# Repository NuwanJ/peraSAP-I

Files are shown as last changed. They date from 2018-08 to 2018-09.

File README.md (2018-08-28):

Image of Yaktocat

## Pera SAP-I Computer

Does anyone have an idea about early computers? The age before Microcontrollers/ Microprocessors? I have just now completed a project that takes me into that time. 

This is an 8-bit Minimum Computer (Computation Machine) [1] that made from simple logic ICs, flip-flops and a few memory modules. It has a memory of 16 bytes and its maximum clock speed is not more than 5 Hz.

The whole design is based on SAP-I Architecture and design was obtained from Ben Eater’s Youtube Channel [2]. Currently, it has 9 instructions (based on Intel 8080 instructions) and can be programmed it using machine language (That means programming from 1s and 0s)

The project was started as a project for CO221: Digital Design Course, Department of Computer Engineering, University of Peradeniya.

All the Printed Circuit boards were designed from the basics by us using Fritzing, fabricated by using the CNC, Builder_V3 and soldered and assembled by us. It took 2 months to complete the fabrications and another month for build motherboard (30x40cm) and debugging.

After the evolution of the project, we hope to make it free and open source under Apache License 2.0

##### Special thanks to
- Dr. Kamalanath Samarakoon for giving the idea & source materials about SAP-I
Dr. S.D. Dewasurendra
- Miss. Narmada Balasooriya, Miss. Thilini Dahanayaka and all the instructors on the Department of Computer Engineering
- My team members; Suneth Samarasinghe, Pubudu Premathilake, Dilshani Karunarathne, Wishma Herath, Pasan Thennakoon & Irfan Mohommad

##### References:
- [Computer algorithms - Wikipedia ](https://en.wikipedia.org/wiki/Algorithm#Computer_algorithms)
- [Building an 8-bit breadboard computer! - Youtube](https://www.youtube.com/playlist?list=PLowKtXNTBypGqImE405J2565dvjafglHU)
- [Open source project files- Github](https://github.com/NuwanJ/peraSAP-I)
 - [Project Page](http://nuwanjaliyagoda.esy.es/projects/8bit-computer)

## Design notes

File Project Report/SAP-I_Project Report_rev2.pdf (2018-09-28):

CO221: Digital Design - Hardware Project

# SAP-I Computer from discrete components

Project Team:

- Jaliyagoda A.J.N.M. (E/15/140)
- Herath H.M.M.E.W.L. (E/15/123)
- Karunarathna S.D.D.D. (E/15/173)
- Samarasinghe U.G.S.B. (E/15/316)
- Premathilaka M.P.U. (E/15/280)
- Irfan M.M.M. (E/15/138)
- Tennakoon T.M.P.B. (E/15/350)

## Contents

1. Introduction
2. Design Procedure
2.1. Modules
2.1.1. Clock Module
2.1.2. Program Counter
2.1.3. Registers
2.1.4. Arithmetic and Logic Unit
2.1.5. Output Register
2.1.6. RAM and Programmer
2.1.7. Control Sequencer
2.1.8. Motherboard and the Data Bus
2.2. Programs and Additional Hardware
2.2.1. EEPROM Programmer
2.2.2. Assembly Language Instructions
3. Results
4. Expenditures
5. Conclusions and future works
6. References
7. Appendix
7.1. Schematics Diagrams
7.2. Project Repository
7.3. Project Page

## 1. Introduction

“SAP” is the shortened form of “Simple As Possible”. SAP-1 is the first stage in the evolution of the modern computers. This design contains all the most essential components of a modern computer and it covers many advanced concepts in Computer Architecture.

SAP-1 is a bus organized computer. All the components are connected with a single 8-bit bus (W) through tri-state buffers.

Specifications:
- 8-bit Bus
- 4-bit Program Counter
- 4-bit Memory Address Register (MAR)
- 16-byte Memory
- 8-bit Instruction Register (IR)
- 5 cycle micro-instructions with 16-bit words
- 8-bit Accumulator
- 8-bit B register
- 8-bit Full Adder/ Subtractor
- 8-bit Output Register

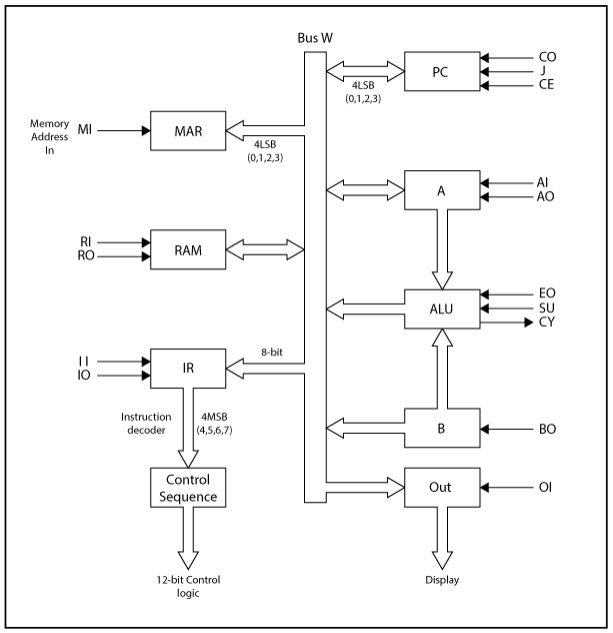
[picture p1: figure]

Figure 1.1: SAP-1 Organization

## 2. Design Procedure

### 2.1 Modules

All the modules were separately designed, fabricated and finally connected each other on a single circuit board; motherboard which includes all the data and signal buses

Here is the list of modules we were designed

- Clock Module
- Program Counter
- Registers (Register A, Register B, Instruction Register)
- Arithmetic and Logic Unit (ALU)
- Output Register
- RAM and Programmer
- Control Sequencer
- Motherboard

All the modules were designed as Printed Circuit Boards (PCB). The design was done by using Fritzing (A open-source PCB designing software) and Fabricated using PCB Milling Machine.

2.1.1 Clock Module

The computer’s clock module is used to synchronize all operations. Basically, there are some methods to implement a clock module for a computer. So this 8-bit computer’s clock module was built based on 555 timer IC.

There are two modes in the clock module.

- A-stable mode: In this mode, clock pulses are generated automatically. The frequency of the clock pulses depends on the capacitance of the capacitor (connected to pin 2) and the resistance of the resistor (connected between pin 6 and 7). A potentiometer and a resistor are connected between pin 6 and 7 of the IC. So by changing the resistance of the potentiometer, the frequency of the clock pulses can be changed.
- Monostable mode: Whenever the user wants to generate clock pulses manually, the monostable mode can be used. But the bouncing effect must be considered. Therefore another 555 timer IC is used to de-bounced the circuit.

Bi-stable mode
There must be a way to switch between astable mode and monostable mode. So the bistable mode is used. Since a toggle switch is used, the circuit must be debounced. Therefore another 555 timer IC is used for that. So the bistable circuit gives a debounced stable output.

Halt Status
When the user wants to halt the computer programmatically, the halt state can be used. Normally the halt input is in law state and it is inverted by a NOT gate. When the HALT instruction was called (in 3rd microinstruction), the circuit was implemented such that the computer halts the execution of instructions.

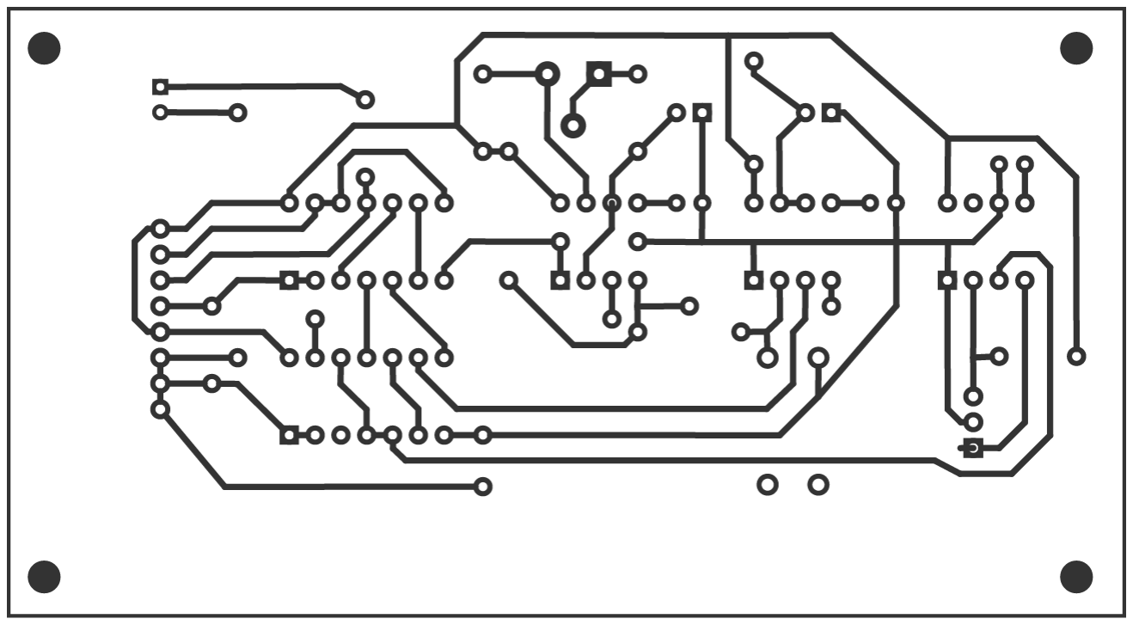
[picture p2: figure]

Figure 2.1: Clock Module (PCB Layout)

2.1.2 Program Counter

The program is stored in the RAM as a listed instruction. In order to execute them, the instructions must be fetched from the RAM. So, the program counter is used to keep track of which address is where. It contains the address or the location of the instruction being executed at the current time.

This is a 4-bit counter as the memory has a 4-bit address. This works similar to register A or register B because, it stores a value, sends and receives values from the bus.

Program counter contains 3 control signals.

- Program count out (CO): Sends the stored value to the bus
- Jump (Program counter in): Normally the program counter counts in order from 0. This signal is used to jump around or to run a loop. When the jump signal is enabled it takes the 4 least significant bits from the bus (as this is a 4-bit program counter) and put it to the program counter. That will be the next address that executes.
- Count enable (increment): To increase the program counter once per instruction cycle, not per clock cycle (because the instruction might take multiple clock cycles). When this is enabled program counter will increase on each clock cycles. So, this signal is enabled to take next instruction (increase the counter value) and then the signal is disabled (store and doesn’t continue the increment while executing that instruction until the next instruction).

74LS161 was used as a synchronous 4-bit binary counter. This chip gives the ability to control the “jump signal” by the “load pin 9” and “count enables signal’ by the “enable pin 7 and 10”. But to the “program counter out signal” a tri-state-logic interface is needed for the bus. So, it can control whether the output of the chip is as the same as the value that going to the bus. For that 74LS245 is used which have tri-state buffers that allow enabling or isolate.

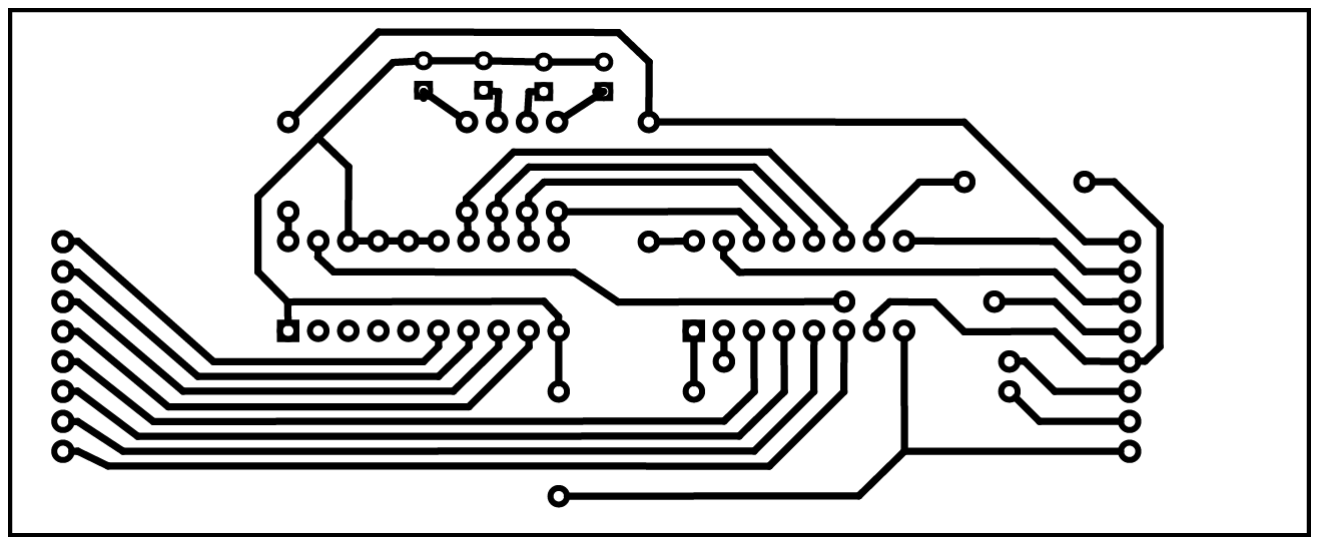
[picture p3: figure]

Figure 2.2: Program Counter (PCB Layout)

2.1.3 Registers

The SAP-1 computer is designed with three similar 8-bit register modules. Two of them, Register A and Register B are reserved for storing two input numbers to the ALU. The other module is the instruction register. Each module has two 4-bit D-type registers and one 8-bit tri-state buffer to connect and disconnect the output stream to the main bus.

Control Signals (Register A and B):
- AI, BI, II: Register input enable
- AO, IO: Register output enable
- RST: Reset memory
- CLK: Clock Signal

Data Buses (Register A and B):
- 8-bit Data In (input) from W Bus
- 8-bit Data Out (output) to W Bus
- 8-bit Data Out (output) to ALU

The instruction register is little different from the two other registers. Its 4 least significant bits are used to store current Instruction and wired to the control unit. Most significant 4 bits are used to store instruction data.

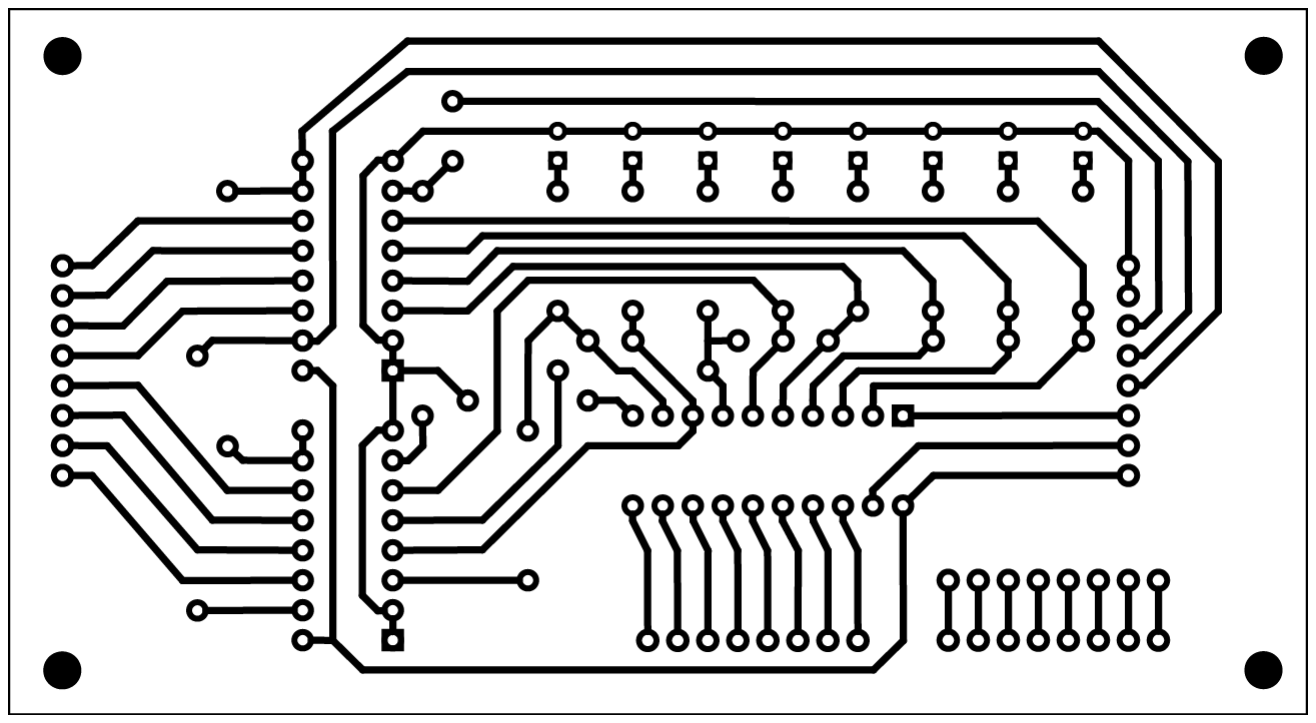
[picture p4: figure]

Figure 2.3: Register (PCB Layout)

2.1.4 Arithmetic and Logic Unit

SAP-I is capable of doing two binary operations and they are addition and subtraction. These mathematical operations are done by the Arithmetic and Logic Unit (ALU). Two registers are used to feed data to the ALU.

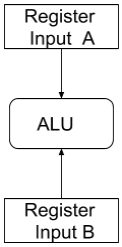
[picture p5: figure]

Figure 2.4: Block Diagram of the ALU

Components

- 74LS283 (4-bit binary full adder with fast carry) x 2
- 74LS245 (Octal bus transceiver) x 1
- 74LS86 (Quad 2-input Exclusive OR gate) x 2

Design
There are 8 input lines to the ALU from both register A and register B. Therefore, two cascaded 4-bit adders are used. If the chosen operation is subtraction the XOR panel is in active state. Thus, ALU gets the inverted value in the register B.

Two inputs addition is typical bitwise addition and there is a specific method used to get the binary subtraction. When the subtracting instruction is given to the computer it calculates the 2’s complement value of the input B and adds it to the input A to get the result A-B

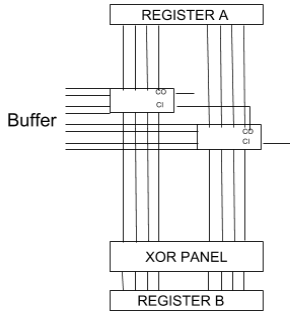
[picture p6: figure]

Figure 2.5: Schematic diagram of the 8-bit ALU

The output lines of adders are directed to the tri-state buffer and the buffer is connected to the main bus.

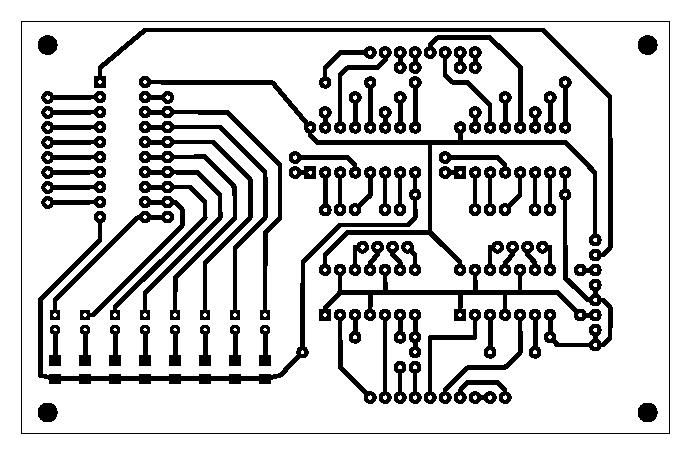
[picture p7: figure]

Figure 2.6: ALU (PCB Layout)

2.1.5 Output Register

The Output Display of the SAP-1 computer is designed to display a decimal representation of an 8-bit binary number (0-255). In this design, we have programmed a single EEPROM to display each of the 3 digits of a given decimal number using four 7-segment displays.

Components
- 1kΩ resistor
- 100kΩ resistor
- 0.01µf capacitor
- 555 timer IC
- 74LS08 (QUAD AND gate)
- 74LS76 (Dual JK flip-flop)
- 74LS139 (Dual 2-line to 4-line decoder)
- 74LS273 (Octal D flip-flop)
- 28C16 EEPROM
- Common Cathode 7-segment display x 4

Design
Initially, we have to create a separate clock pulse for the output display that runs at a different speed than the SAP-1 computer. To do this we use a 555 timer connected with a 0.01µF capacitor, a 100kΩ resistor, and a 1kΩ resistor.

We wanted to drive four 7-segment displays sequentially. To do that we wanted a ring counter. We used a 74LS76 IC which include two JK flip-flops. By feeding the output of the first flip-flop to the clock of the second flip-flop we can create a counter which counts from zero to three in binary and that controls which 7 segment display turned on in given time.

After that we need to program the EEPROM to display a certain digit at a certain time at each of the display to create the illusion of the number is displayed continuously without any delay.

The output of the A register has to connect to 8 of the address lines of the EEPROM to input the register the number which is needed to display, leaving 3 empty address lines. By connecting the 2 outputs of the counter to a two remaining address lines we can program the EEPROM to display each digit of the decimal value of the number inputted to the EEPROM using three 7-segments displays (We leave the remaining display empty for this circuit, but hope to use it to display negative numbers with 2s complement notation).

This allows the 7-segment displays to display each digit of the inputted value at each clock pulse in all of the 7-segment displays. Therefore we need a way to keep only the appropriate display on while all of the other displays are at off state for a single clock pulse, therefore, each of the display shows the appropriate digit of the number. To do that we use a 74LS139 decoder. By connecting the two outputs of the counter to the inputs of the decoder we can create a cyclic pulse that goes low at each output in turn. By connecting outputs of the decoder to the four 7-segment displays, we can make the displays to show the appropriate digit of the number inputted to the EEPROM, therefore, creating the display of the SAP-1 computer.

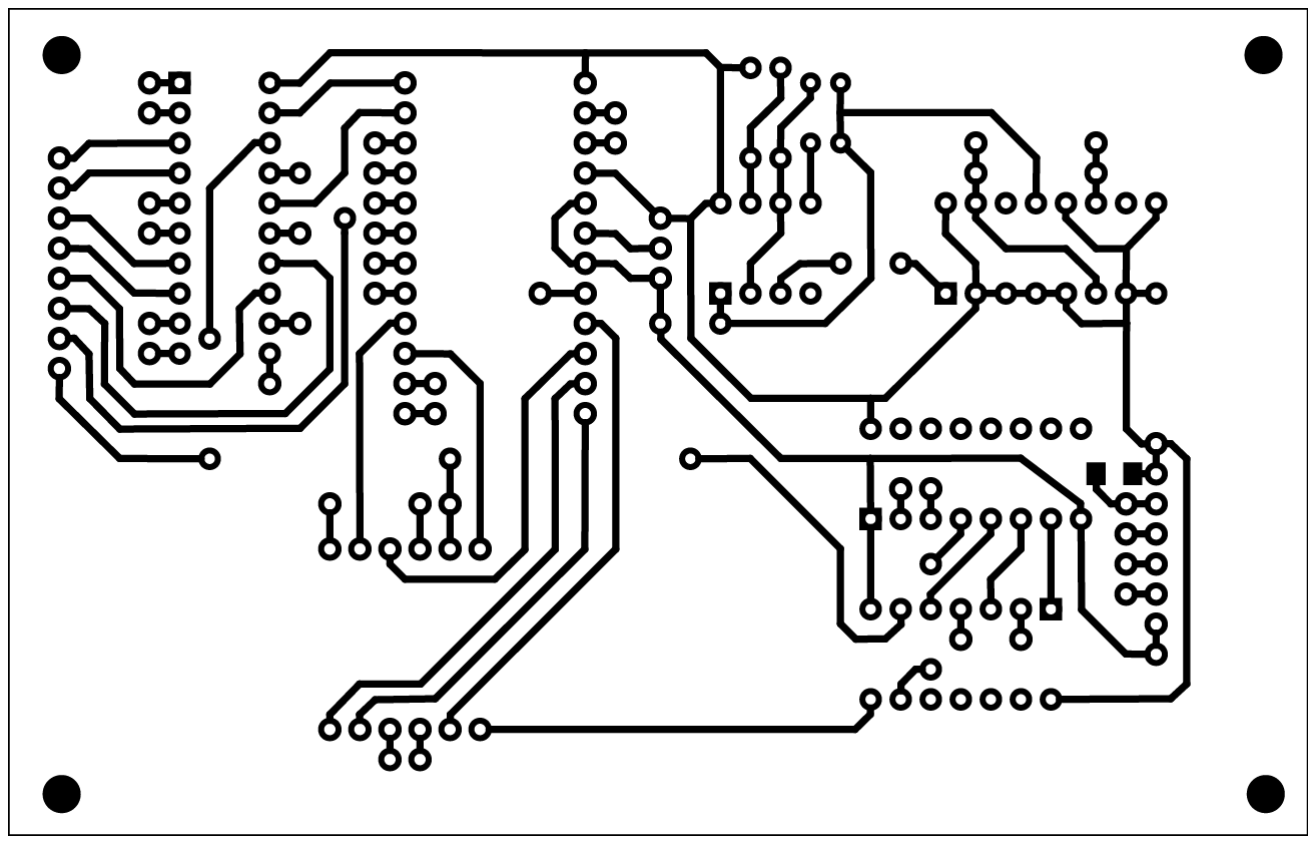
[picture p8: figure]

Figure 2.7: Output Register (PCB Layout)

2.1.6 RAM and Programmer

RAM is the module contains all the instructions and it should be programmable from outside. That means the inputs for the RAM may be given through W bus or Manual Switches.

To fulfill this requirement, RAM was designed as two separate modules, Programmer and Memory module.

3.1.6.1 Programmer
The programmer contains 2:1 multiplexer (74LS157) for 4 address bits and for 8 data bits. A toggle switch was used as the control signal for the multiplexer. When it is pressed, module acts as a programmer and input can be gives using small DIP switches. When the toggle button was released, it acts as regular RAM and inputs were taken from the W bus. Memory Address Register also contains in the Programmer Module.

Control Signals:
- ~W: Write memory address (output signal)
- RI: RAM In
- CLK: Clock
- ~MI: Memory address in

Data Buses:
- 4-bit Address (output) to RAM
- 8-bit Word (output) to RAM
- 8-bit Data In (input) from W Bus

3.1.6.2 RAM Memory

Memory module contains two 74LS189 4-bit RAM ICs. 74LS189 has inverted output pins, so all the outputs were inverted using 74LS04 ICs and connected to W Bus through 74LS245 tri-state buffer.

Control Signals:
- ~RO: RAM Out
- ~W: Write memory address

Data Buses:
- 4-bit Address (input) from Programmer
- 8-bit Data Out (output) to W Bus

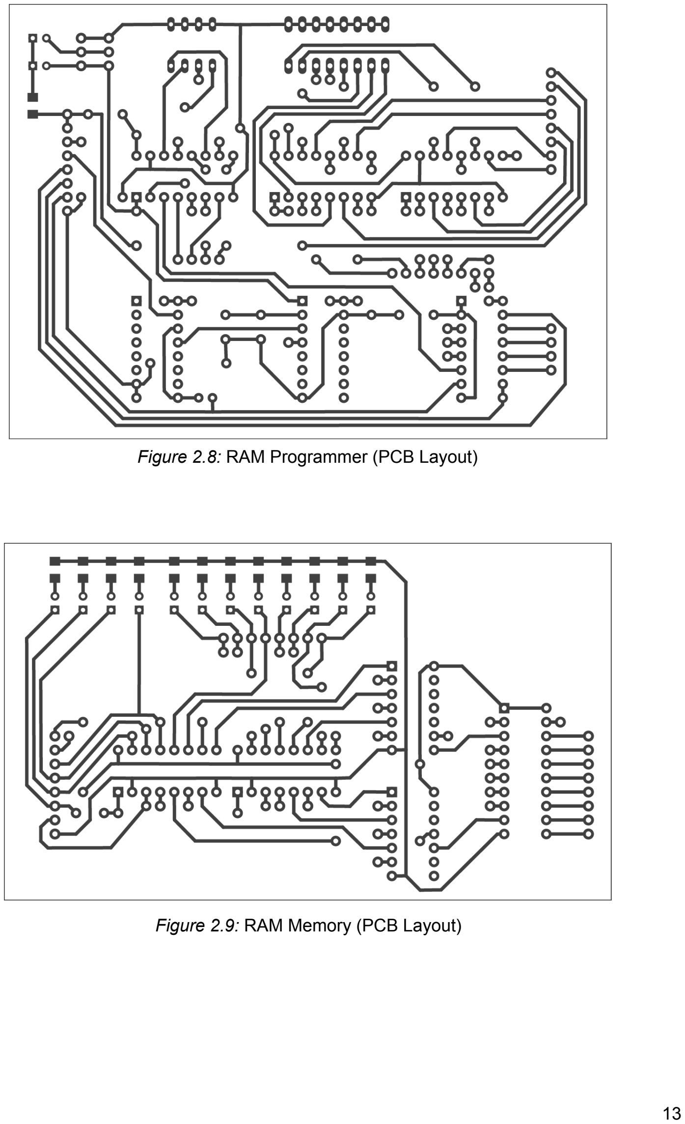
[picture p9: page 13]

Figure 2.8: RAM Programmer (PCB Layout)

Figure 2.9: RAM Memory (PCB Layout)

2.1.7 Control Sequencer

Control Sequencer is the module that controls all other modules in the SAP-1 computer. Instructions were given from RAM and sequencer contains internal ring counter to execute 5 microinstructions itself.

In addition to providing control signals, it contains a reset switch, which can be used to reset the computer by clearing all memory elements.

Control Sequencer was designed as two modules. The first one contains pre-programmed EEPROM to output control signals for given instruction and microinstruction signals. The second module is for invert control signals if destination module works on active low condition. It acts as an indicator of control signals too.

Inputs/Outputs:
- 4-bit Instruction (input) from Instruction Register
- 12-bit Control Signal (output)
- Reset. ~Reset signals

Control Signals:
- HLT: Standby the computer
- MI: Memory Address In
- RI: RAM In
- RO: RAM Out
- IO: Instruction Register Out
- II: Instruction Register In
- AI: Register A In
- AO: Register A Out
- ZO: ALU Out
- SU: Subtract
- BI: Register B In
- OE: Output Enable
- CE: Counter Enable
- CO: Counter Out
- J: Jump
- X: Unused Pin

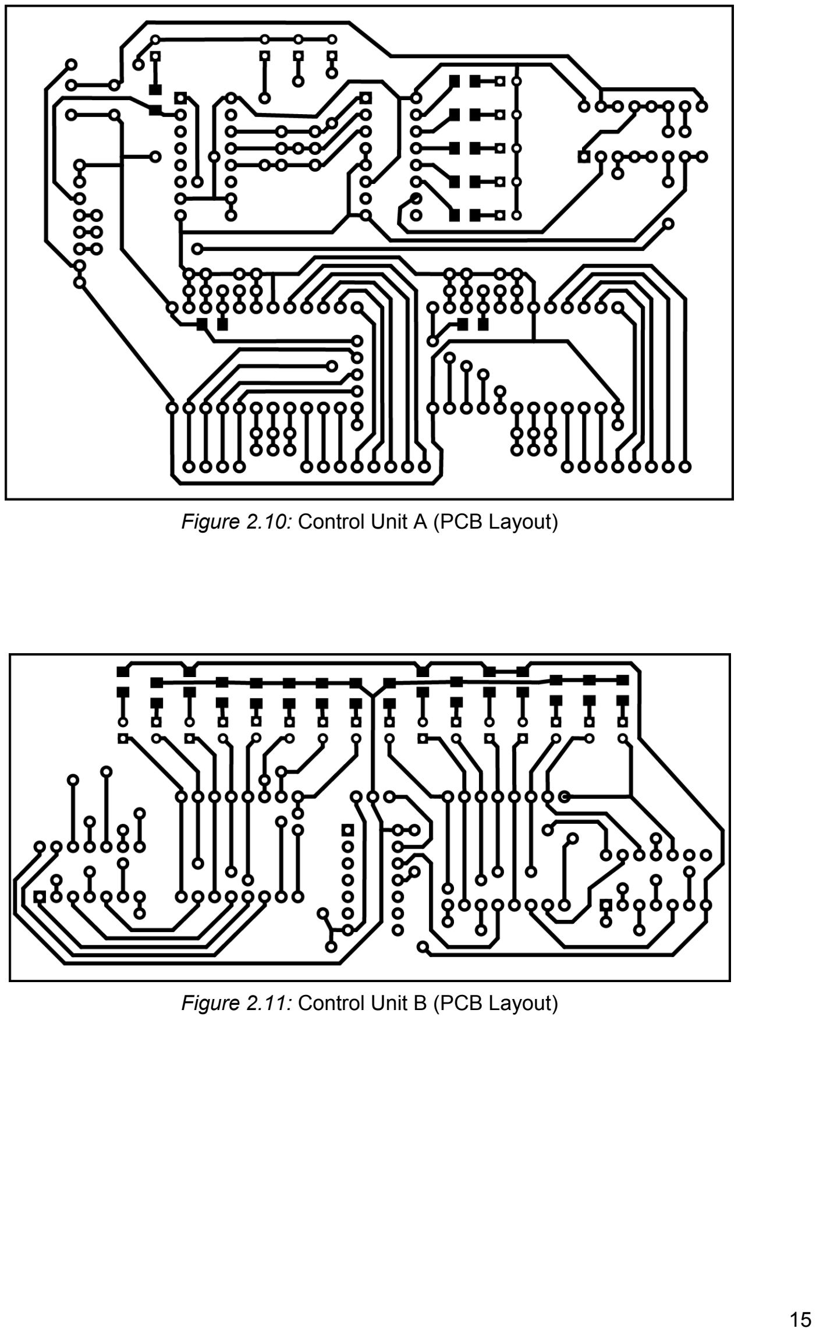
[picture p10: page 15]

Figure 2.10: Control Unit A (PCB Layout)

Figure 2.11: Control Unit B (PCB Layout)

2.1.8 Motherboard and Data Bus

We have designed 12 separate modules and wanted a way to connect these all modules. Therefore we designed a motherboard, which has dimensions of 300mm x 430mm. Due to its size, no way to make it as a printed circuit board. As a solution, we choose a plastic board and milled slots to pass the control and data pins from each module to the bottom and wired and soldered them using single core copper wires.

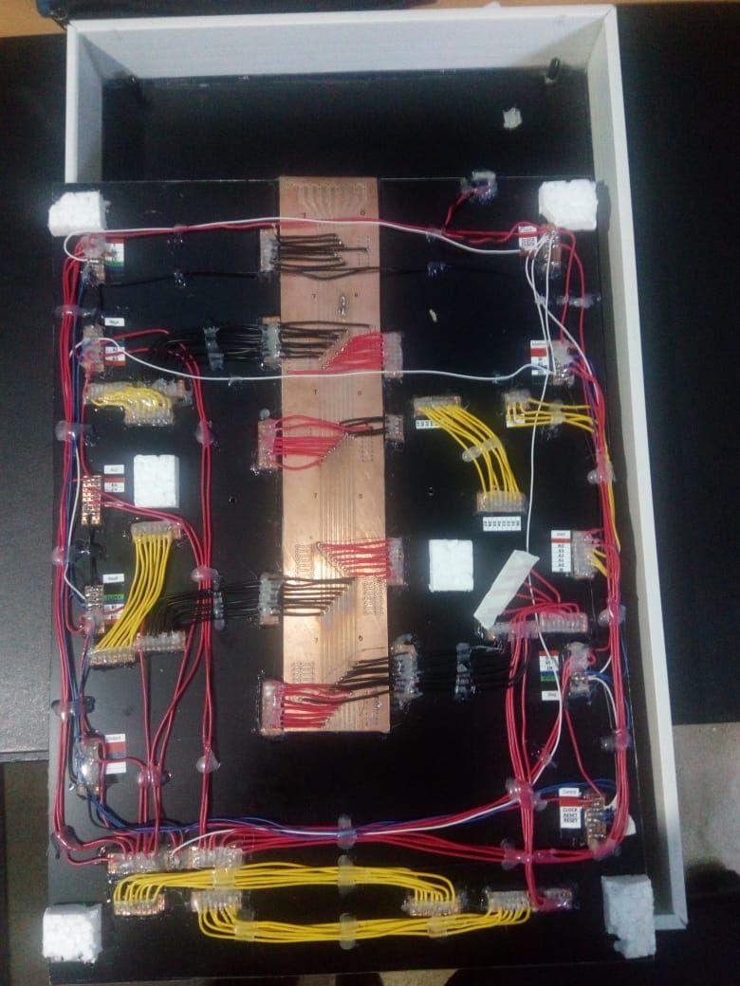
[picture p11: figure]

Figure 2.12: A picture of the wirings on the bottom of the motherboard

### 2.2 Programs and Additional Hardware

We were designed few additional hardware/software which was not included in final the prototype.

2.2.1 EEPROM Programmer

We wanted to program 2kB EEPROM which has 11 address bits and 8 data bits. Therefore we decided to make an EEPROM Programmer using Arduino Mega board (which has 54 digital IO pins)

2.2.2 Assembly Language Instructions

We made a truth table for each instruction and its microinstruction with 15 control signals.

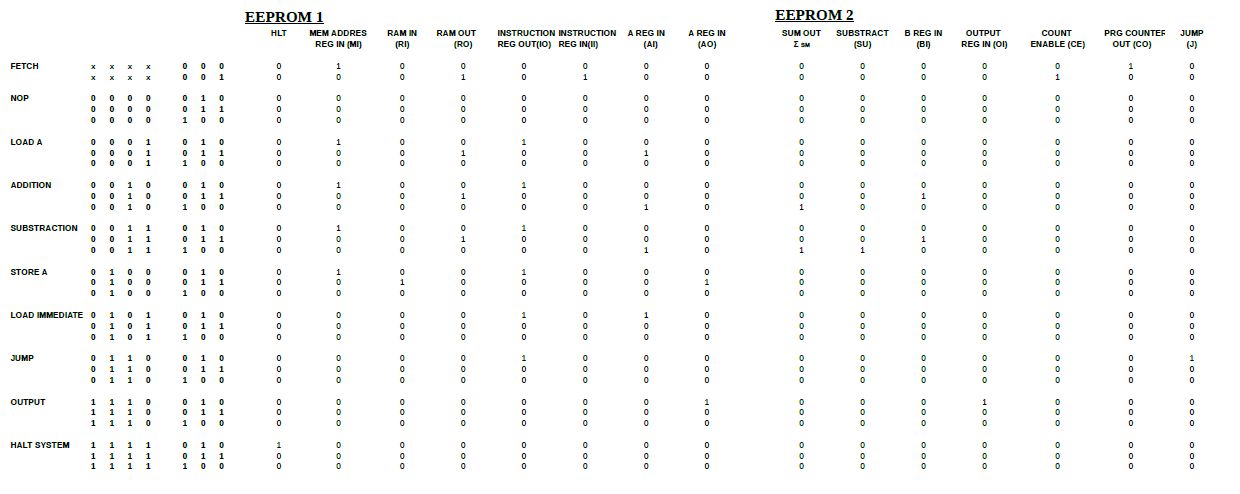
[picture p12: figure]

Figure 2.13: The Table we prepared for each instruction

Truth table was programmed into two 28C16 EEPROMs using the EEPROM Programmer we designed with Arduino Mega Board.

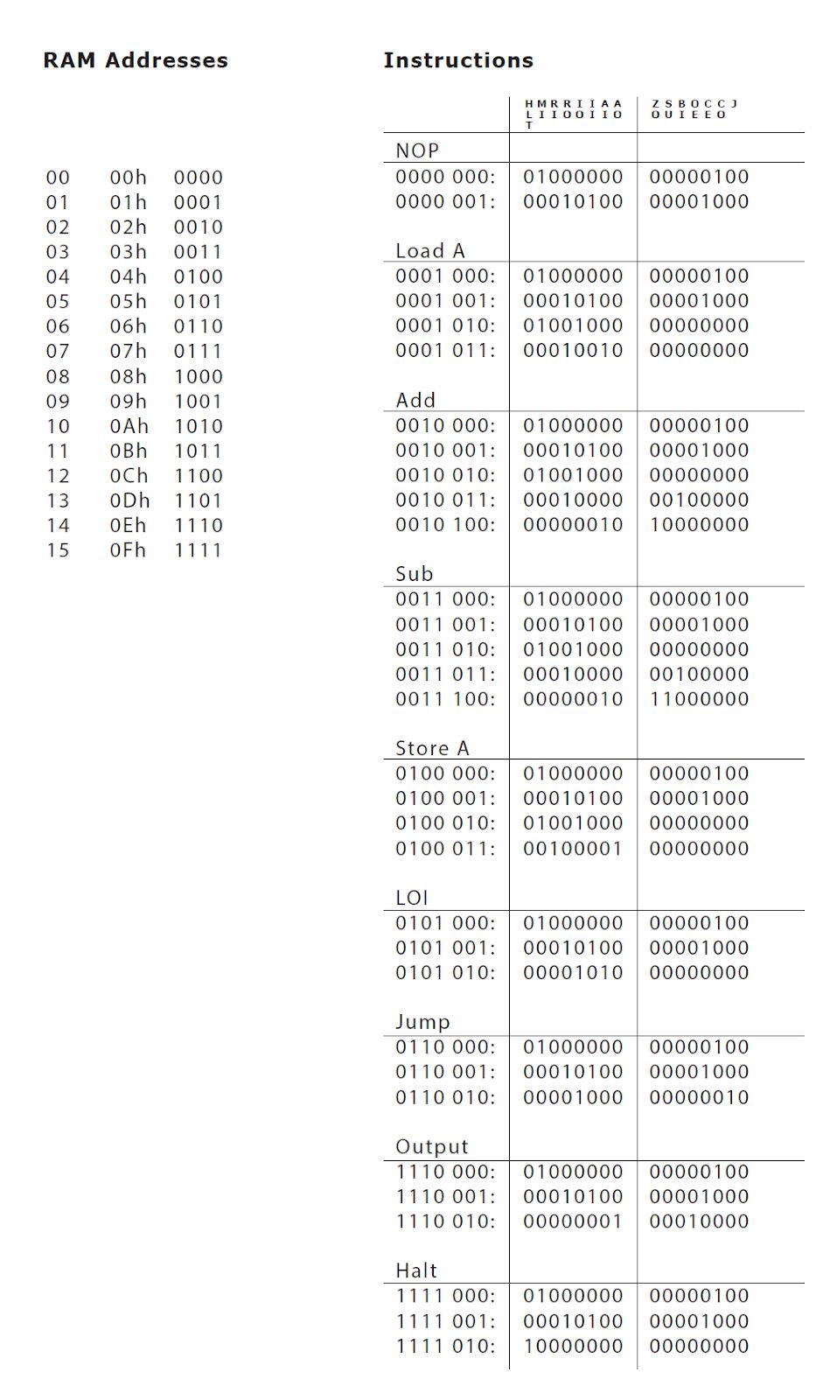
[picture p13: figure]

Figure 2.14: Finalized instruction sheet

## 3. Results

SAP-1 design can add or subtract two numbers, run an infinite loop by executing a given instruction sequence.

Sample Program:

Shows 100 in the display and increase the value shown in it by 7 infinitely.

N = 100;
print(N);
while(1) {
N = N + 7;
print(N);
}
Address | Assembly Code | Machine Code
0000 | LDA 9h | 0001 1001
0001 | OUT | 1110 xxxx
0010 | ADD Ah | 0010 1010
0011 | OUT | 1110 xxxx
0100 | JUMP 2h | 0110 0010
… | … | ...
1001 | 100 | 0110 0100
1010 | 7 | 0000 0111

## 4. Expenditures

Here is the rough expenditures of our project.

Component | Unit Price | Quantity | Total
NE555 | 20.00 | 4 | 80.00
74LS00 | 35.00 | 2 | 70.00
74LS02 | 40.00 | 1 | 40.00
74LS04 | 40.00 | 5 | 200.00
74LS08 | 40.00 | 3 | 120.00
74LS32 | 35.00 | 1 | 35.00
74LS76 | 161.00 | 1 | 161.00
74LS86 | 40.00 | 2 | 80.00
74LS138 | 25.00 | 1 | 25.00
74LS139 | 40.00 | 1 | 40.00
74LS157 | 78.00 | 4 | 312.00
74LS161 | 27.00 | 4 | 108.00
74LS173 | 77.00 | 8 | 616.00
74LS189 | 89.00 | 2 | 178.00
74LS245 | 35.00 | 6 | 210.00
74LS273 | 70.00 | 1 | 70.00
74LS283 | 80.00 | 2 | 160.00
28C16 | 250.00 | 3 | 750.00
LED (3mm) | 1.50 | 56 | 84.00
Copper Boards | 265.00 | 2 | 530.00
Single Core Wire | 15.00 | 25 | 375.00
7 Segment Display | 130.00 | 1 | 130.00
Solder (0.8mm) | 20.00 | 20 | 400.00
Long Leg Headers | 6.00 | 15 | 90.00
Pin Headers | 10.00 | 5 | 50.00
IC Bases (8 pin) | 3.50 | 4 | 14.00
IC Bases (14 pin) | 8.00 | 15 | 120.00
IC Bases (16 pin) | 10.00 | 27 | 270.00
IC Bases (20 pin) | 10.00 | 7 | 70.00
IC Bases (28 pin) | 12.00 | 6 | 72.00
Total | | | 5460.00

## 5. Conclusions and future works

We hope to add a Flag Register and give an ability to compare values and make conditional jumps. Then we can write programs which have selections (if structure)

Current clock module generates clock pulses on very small frequency range (0.5Hz to 2Hz) and unable to operate in high frequencies. We hope to increase the clock frequency and make it faster.

We hope to improve current design and upgrade it into SAP-II computer which has more instructions and better features.

## 6. References

1. Digital Computer Electronics Third Edition, 1999, McGraw-Hills Albers Paul and Jerald A. Brown
2. Build an 8-bit computer from scratch
https://eater.net/8bit
3. Youtube: Building an 8-bit breadboard computer https://www.youtube.com/playlist?list=PLowKtXNTBypGqImE405J2565dvjafglHU
4. 74 Series IC Datasheets http://www.skot9000.com/ttl/

## 7. Appendix

7.1 Schematics Diagrams

7.1.1 Program Counter

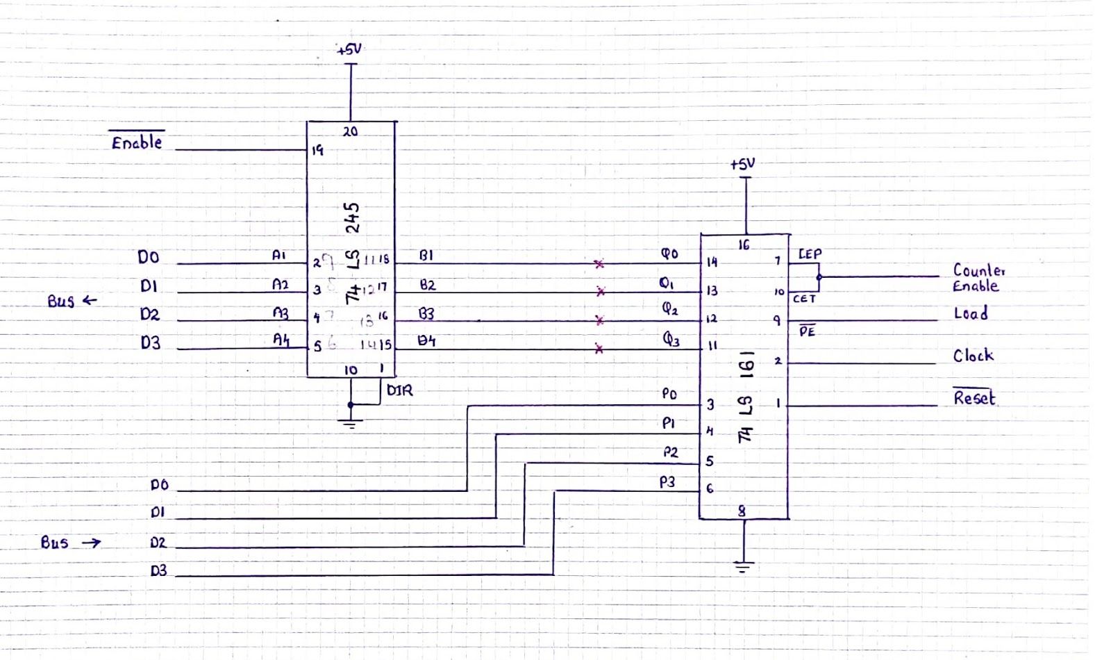
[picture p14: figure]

7.1.2 Register

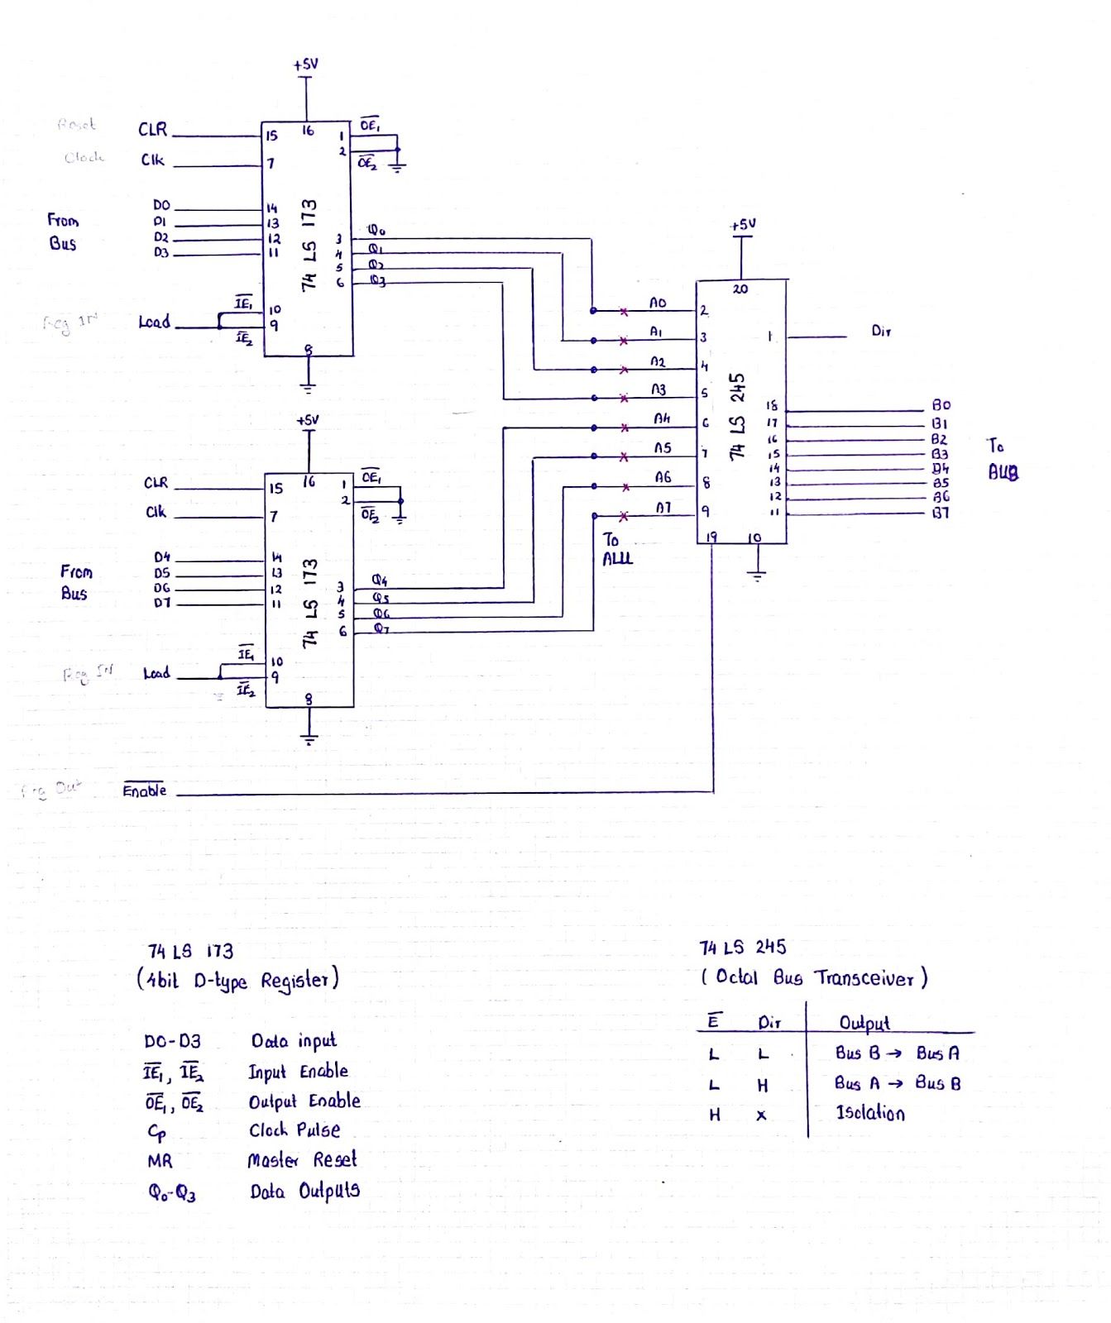
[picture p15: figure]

7.1.3 ALU

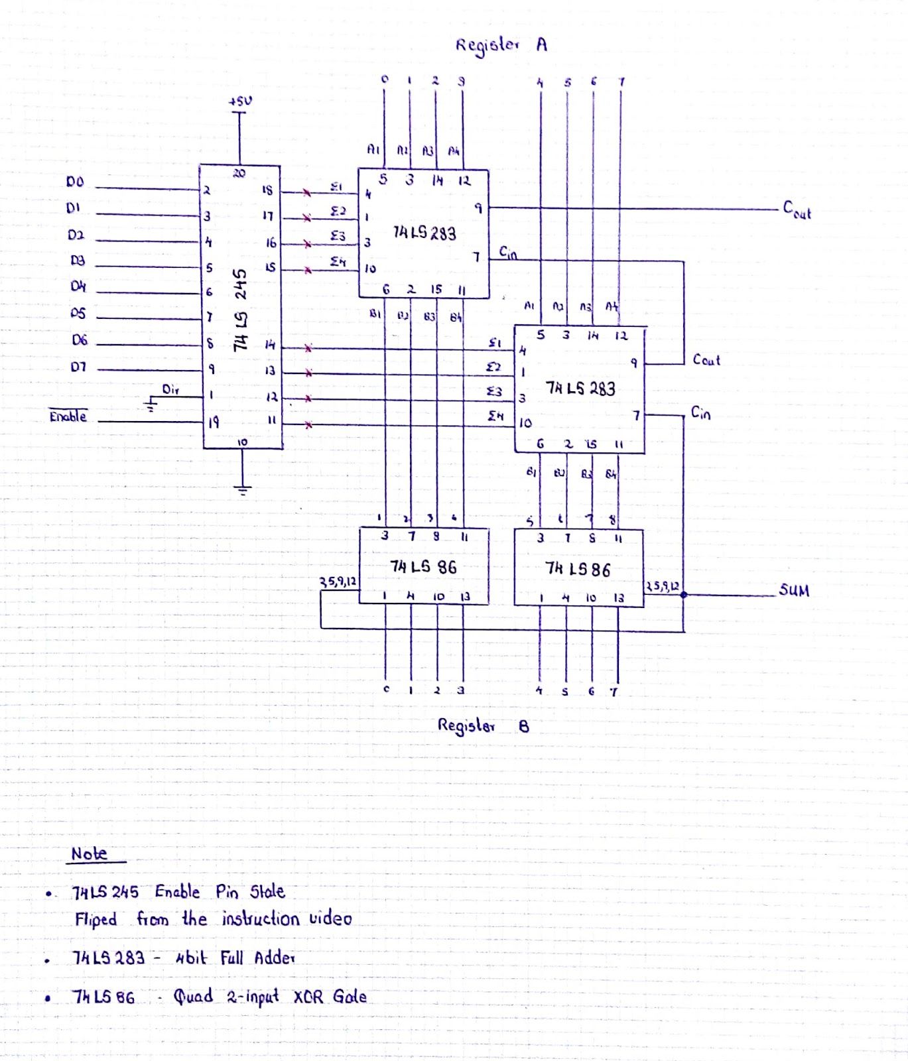
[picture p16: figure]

7.2 Project Repository

https://github.com/NuwanJ/peraSAP-I (open-source under Apache License 2.0)

7.3 Project Page

http://nuwanjaliyagoda.com/projects/8bit-computer

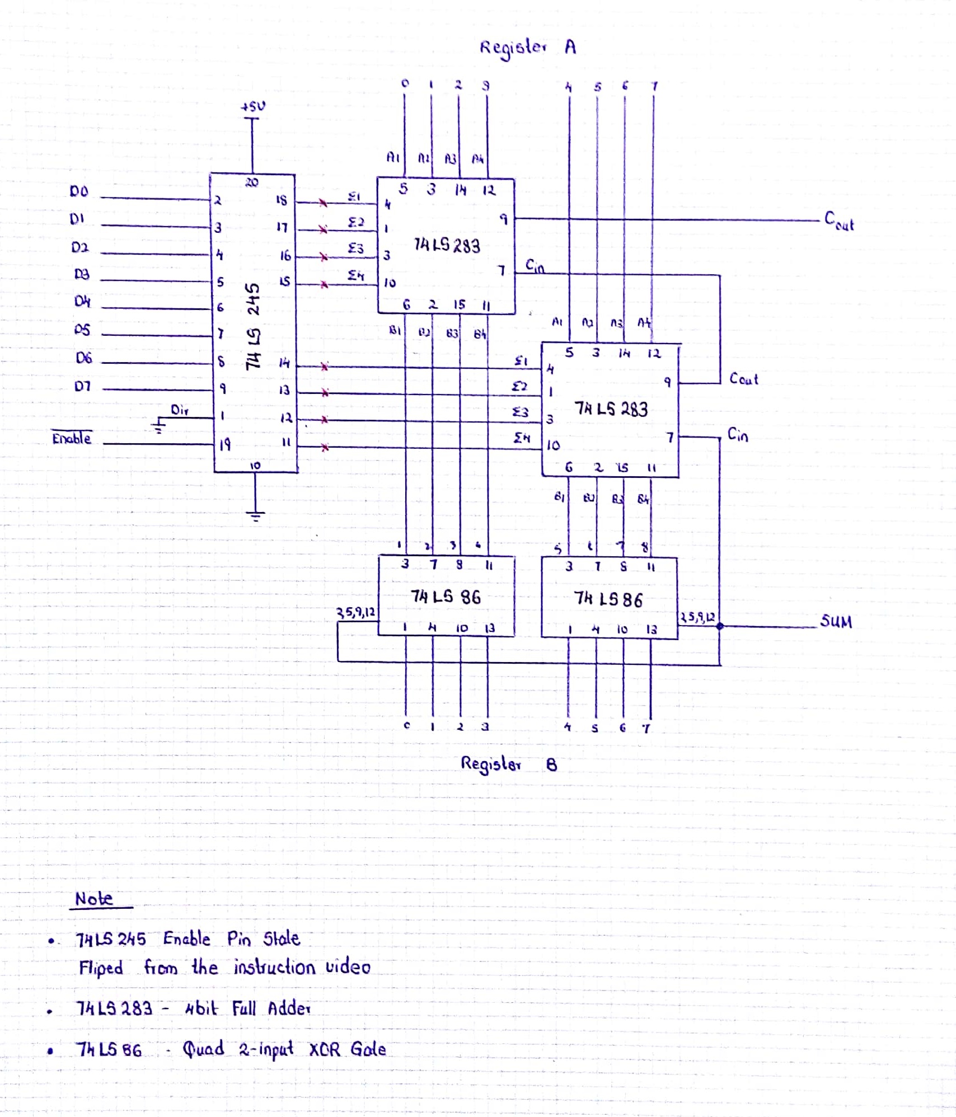
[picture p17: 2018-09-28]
Schematics/alu.jpg

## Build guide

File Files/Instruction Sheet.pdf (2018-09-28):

NOP
0000 000: | 01000000 | 00000100
0000 001: | 00010100 | 00001000

Load A
0001 000: | 01000000 | 00000100
0001 001: | 00010100 | 00001000
0001 010: | 01001000 | 00000000
0001 011: | 00010010 | 00000000

Add
0010 000: | 01000000 | 00000100
0010 001: | 00010100 | 00001000
0010 010: | 01001000 | 00000000
0010 011: | 00010000 | 00100000
0010 100: | 00000010 | 10000000

Sub
0011 000: | 01000000 | 00000100
0011 001: | 00010100 | 00001000
0011 010: | 01001000 | 00000000
0011 011: | 00010000 | 00100000
0011 100: | 00000010 | 11000000

Store A
0100 000: | 01000000 | 00000100
0100 001: | 00010100 | 00001000
0100 010: | 01001000 | 00000000
0100 011: | 00100001 | 00000000

LOI
0101 000: | 01000000 | 00000100
0101 001: | 00010100 | 00001000
0101 010: | 00001010 | 00000000

Jump
0110 000: | 01000000 | 00000100
0110 001: | 00010100 | 00001000
0110 010: | 00001000 | 00000010

Output
1110 000: | 01000000 | 00000100
1110 001: | 00010100 | 00001000
1110 010: | 00000001 | 00010000

Halt
1111 000: | 01000000 | 00000100
1111 001: | 00010100 | 00001000
1111 010: | 10000000 | 00000000

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
00 | 00h 0000
01 | 01h 0001
02 | 02h 0010
03 | 03h 0011
04 | 04h 0100
05 | 05h 0101
06 | 06h 0110
07 | 07h 0111
08 | 08h 1000
09 | 09h 1001
10 | 0Ah 1010
11 | 0Bh 1011
12 | 0Ch 1100
13 | 0Dh 1101
14 | 0Eh 1110
15 | 0Fh 1111
RAM Addresses | Instructions

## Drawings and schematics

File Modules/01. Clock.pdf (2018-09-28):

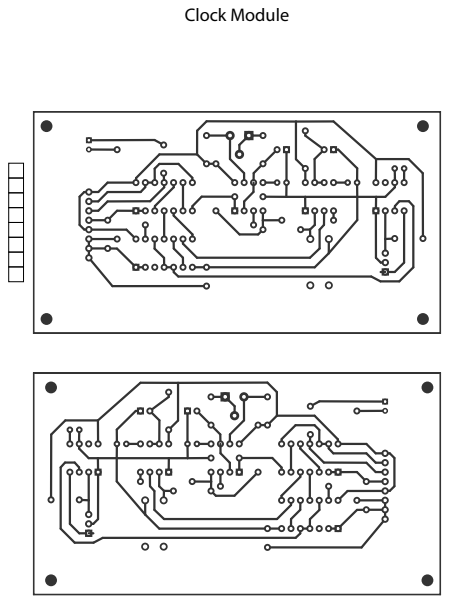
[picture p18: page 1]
Clock Module

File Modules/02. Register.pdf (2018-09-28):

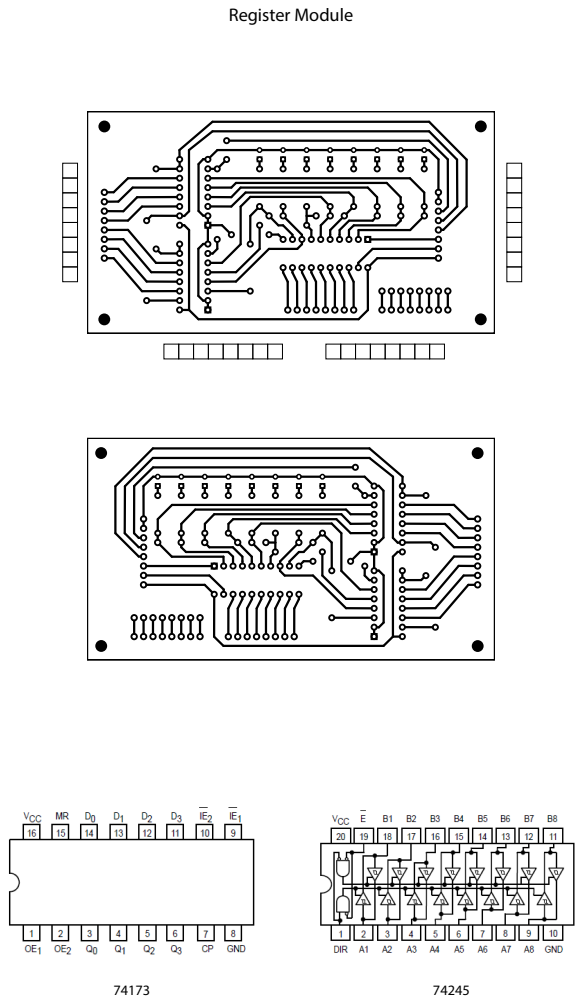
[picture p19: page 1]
Register Module

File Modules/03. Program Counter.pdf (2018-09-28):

Register Module

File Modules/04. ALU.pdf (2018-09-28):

## ALU Module

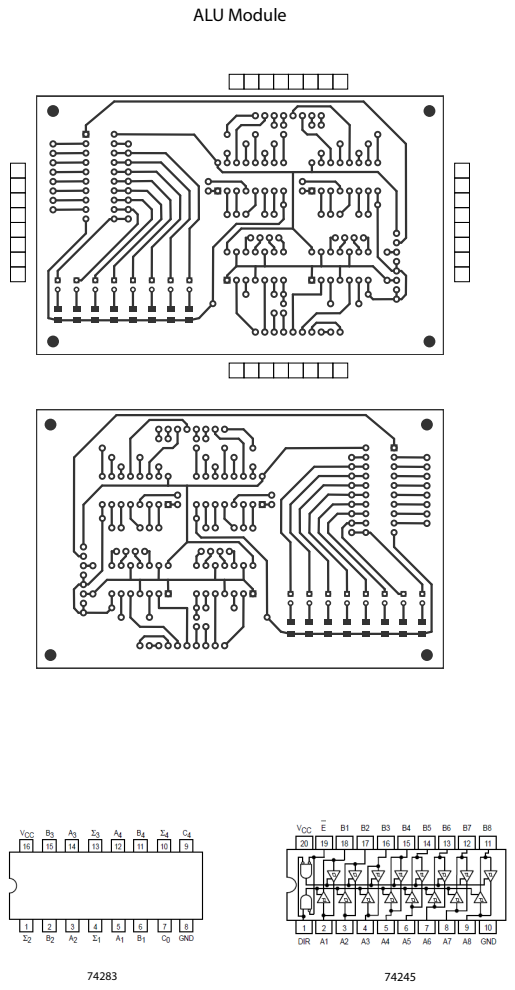
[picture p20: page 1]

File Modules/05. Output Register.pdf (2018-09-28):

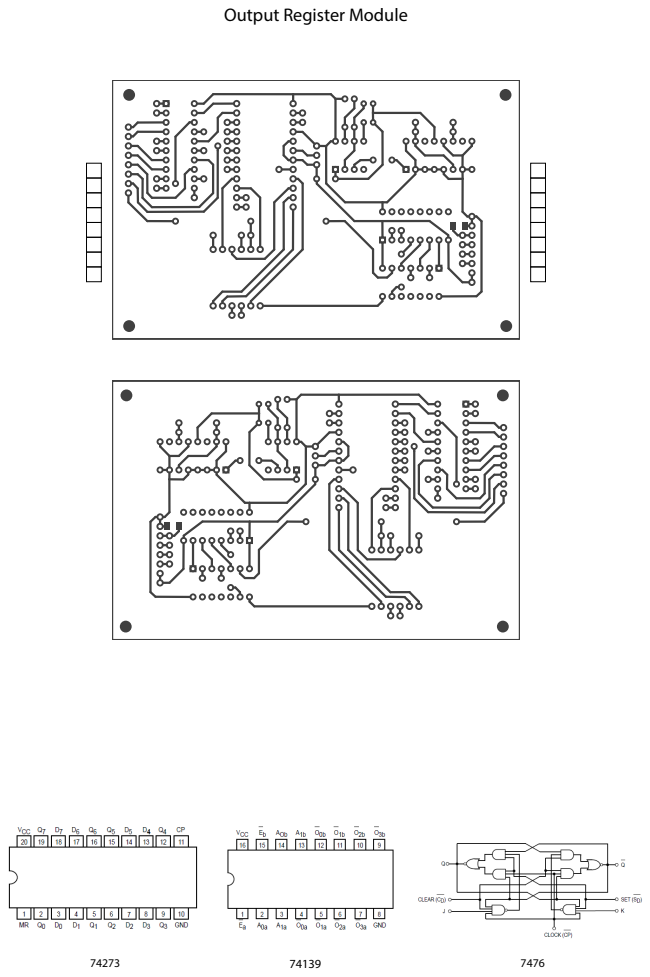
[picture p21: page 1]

Output Register Module

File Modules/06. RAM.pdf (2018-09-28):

## RAM Module

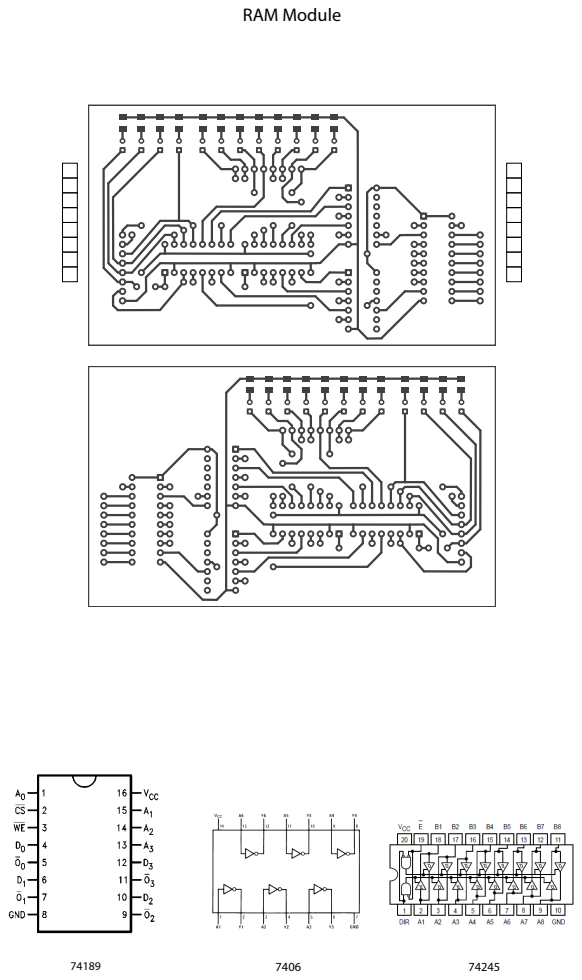
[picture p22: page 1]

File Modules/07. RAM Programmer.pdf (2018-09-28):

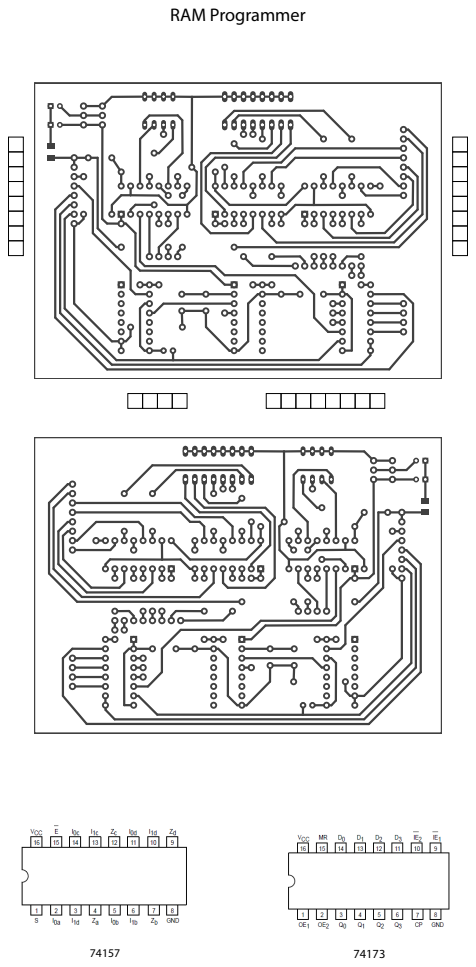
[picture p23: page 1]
RAM Programmer

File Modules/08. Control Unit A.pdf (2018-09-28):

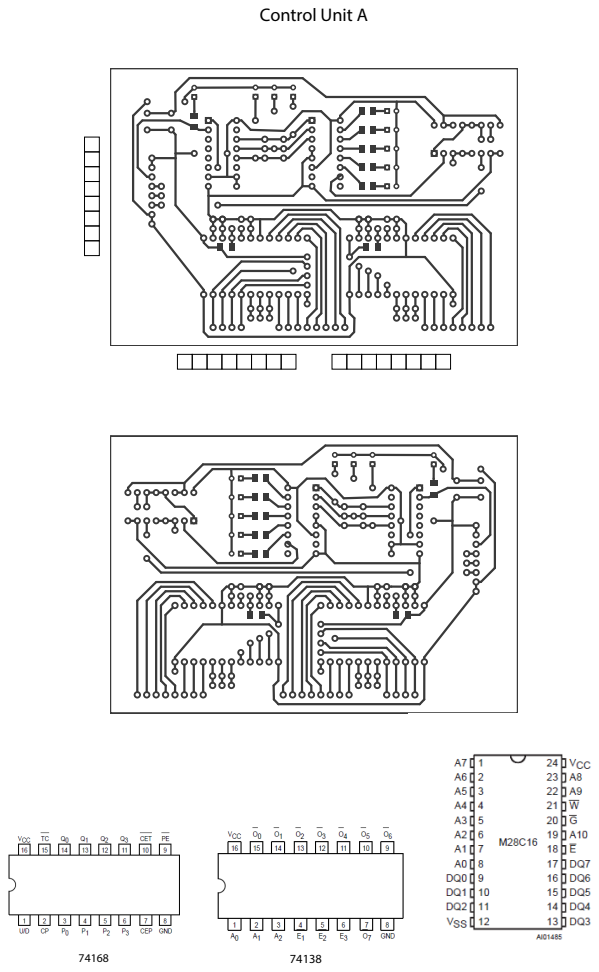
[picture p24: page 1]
Control Unit A

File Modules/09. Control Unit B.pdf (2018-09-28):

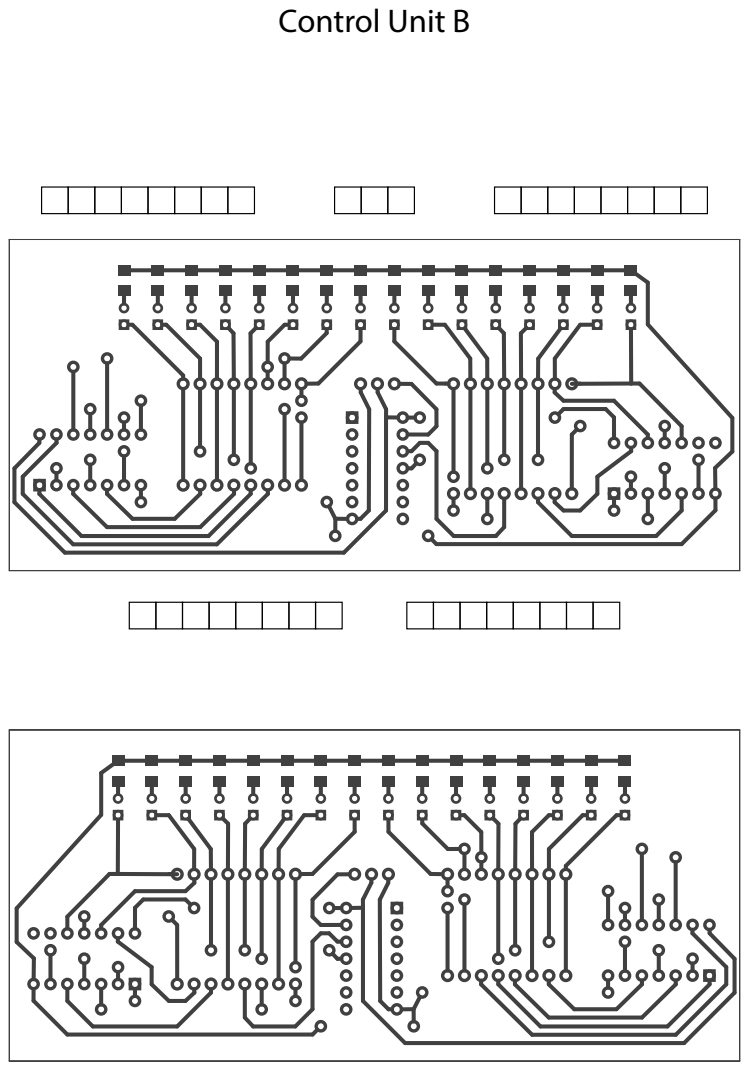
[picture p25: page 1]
Control Unit B

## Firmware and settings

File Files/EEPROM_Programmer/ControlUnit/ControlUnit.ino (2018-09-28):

//          E   G   W
//  Read    0   0   1
//  Write   0   1   0

#define HLT  0b1000000000000000
#define MI   0b0100000000000000
#define RI   0b0010000000000000
#define RO   0b0001000000000000
#define IO   0b0000100000000000
#define II   0b0000010000000000
#define AI   0b0000001000000000
#define AO   0b0000000100000000

#define SM   0b0000000010000000
#define SU   0b0000000001000000
#define BI   0b0000000000100000
#define OI   0b0000000000010000
#define CE   0b0000000000001000
#define CO   0b0000000000000100
#define J    0b0000000000000010
#define XX   0b0000000000000000

const int addPins[] = {14, 15, 16, 17, 20, 19, 18}; // A0-A7

const int outPins[] = {
  22, 24, 26, 28, 30, 32, 34, 36, // IC 1
  38, 40, 42, 44, 46, 48, 50, 52  // IC 2
};

const int pinW = 6, pinW2 = 4, pinG = 5, pinG2 = 3, pinE = 9;

//   -------> Machine Cycle
// |
// | Instruction Cycle
// v

uint16_t data[] = {
  MI | CO,    RO | II | CE,   XX,         XX,         XX,           XX,   XX,   XX,    //0000 -NOP
  MI | CO,    RO | II | CE,   MI | IO,    RO | AI,    XX,           XX,   XX,   XX,    //0001 -LOAD A
  MI | CO,    RO | II | CE,   MI | IO,    RO | BI,    AI | SM,      XX,   XX,   XX,    //0010 -ADDITION
  MI | CO,    RO | II | CE,   MI | IO,    RO | BI,    AI | SM | SU, XX,   XX,   XX,    //0011 -SUBSTRACTION
  MI | CO,    RO | II | CE,   MI | IO,    RI | AO,    XX,           XX,   XX,   XX,    //0100 -STORE A
  MI | CO,    RO | II | CE,   IO | AI,    XX,         XX,           XX,   XX,   XX,    //0101 -LOAD IMMEDIATE
  MI | CO,    RO | II | CE,   IO | J,     XX,         XX,           XX,   XX,   XX,    //0110 -JUMP
  MI | CO,    RO | II | CE,   XX,         XX,         XX,           XX,   XX,   XX,    //0111
  MI | CO,    RO | II | CE,   XX,         XX,         XX,           XX,   XX,   XX,    //1000
  MI | CO,    RO | II | CE,   XX,         XX,         XX,           XX,   XX,   XX,    //1001
  MI | CO,    RO | II | CE,   XX,         XX,         XX,           XX,   XX,   XX,    //1010
  MI | CO,    RO | II | CE,   XX,         XX,         XX,           XX,   XX,   XX,    //1011
  MI | CO,    RO | II | CE,   XX,         XX,         XX,           XX,   XX,   XX,    //1100
  MI | CO,    RO | II | CE,   XX,         XX,         XX,           XX,   XX,   XX,    //1101
  MI | CO,    RO | II | CE,   AO | OI,    XX,         XX,           XX,   XX,   XX,    //1110 -OUTPUT
  MI | CO,    RO | II | CE,   HLT,        XX,         XX,           XX,   XX,   XX     //1111 -HALT SYSTEM
};

void setup() {

  // Output Pins
  for (int i = 0; i < 16; i++) {
    pinMode(outPins[i], OUTPUT);
  }

  // Address Pins
  for (int i = 0; i < 7; i++) {
    pinMode(addPins[i], OUTPUT);
  }

  // Control Pins, default=Read
  pinMode(pinW, OUTPUT);
  pinMode(pinG, OUTPUT);
  pinMode(pinW2, OUTPUT);
  pinMode(pinG2, OUTPUT);
  pinMode(pinE, OUTPUT);

  digitalWrite(pinE, LOW);
  digitalWrite(pinG, LOW);
  digitalWrite(pinW, HIGH);
  digitalWrite(pinG2, LOW);
  digitalWrite(pinW2, HIGH);

  setReadMode();

  Serial.begin(115200);
  delay(1000);

  Serial.println(">> EEPROM: R/W Programmer");
  Serial.println("  begin...");

}

void loop() {

}


void serialEvent() {
  while (Serial.available()) {
    char inChar = (char)Serial.read();

    if (inChar == '+') {
      writeData();
    } else if (inChar == '-') {
      readData();
    } else if (inChar == '*') {
      debug();
    } else if (inChar >= 'A' && inChar <= 'z') {

      char address[8] = {};
      char binary[17] = {};

      uint16_t dataRead = 0;
      uint16_t dataWrite = 0;
      int temp = 0;

      address[7] = '\0';
      binary[16] = '\0';

      //-----------------------------------------------------------------------------
      for (int ii = 0; ii < 5; ii++) {
        // Write the current address

        //-----------------------------------------------------------------------------
        if (inChar >= 'a') {

          temp = (inChar - 'a') * 8 + ii;
          writeAddress(temp);

          // Read mode
          setReadMode();
          if (ii == 0)Serial.println(">> Read");
          dataRead = readOutput();

        } else {

          temp = ((inChar - 'A') * 8) + ii;
          writeAddress(temp);

          // Write mode
          if (ii == 0)Serial.println(">> Write");
          setWriteMode();
          delay(10);

          dataWrite = data[temp]; //ii + (8 * ii) + (128 * ii); //
          dataRead =  dataWrite;
          writeOutput(dataWrite);

        }
        //-----------------------------------------------------------------------------
        Serial.print("addr  >\t");
        Serial.print(temp);
        Serial.print("\t");

        for (int k = 0; k < 7; k++) {
          address[k] = (bitRead(temp, 6 - k) == 1) ? '1' : '0' ;
          if (k == 4)Serial.print(' ');
          Serial.print(address[k]);
        }
        Serial.print(":\t");

        //-----------------------------------------------------------------------------
        for (int k = 0; k < 16; k++) {

          binary[k] = (bitRead(dataRead, 15 - k) == 1) ? '1' : '0' ;
          if (k == 8)Serial.print(' ');
          Serial.print(binary[k]);
        }
        Serial.print("\n");
      }
    }
    Serial.print("\n");

  }
}

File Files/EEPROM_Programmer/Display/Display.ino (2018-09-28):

//          E   G   W
//  Read    0   0   1
//  Write   0   1   0



void writeAddress(int data);
byte readOutput();
void writeOutput(byte data);

//const int outPins[] = {32, 30, 28, 26, 27, 29, 31, 33, 35};
//const int addPins[] = {34, 36, 38, 40, 42, 44, 46, 48, 52, 50, 45};

const int outPins[] = {22, 24, 26, 28, 30, 32, 34, 36};
const int addPins[] = {38, 40, 42, 44, 46, 48, 50, 52, 43, 45, 47};

//const int pinW = 49, pinG = 47, pinE = 43;
const int pinW = 8, pinG = 10, pinE = 9;

const byte digits[] = {
  0x3F, 0x06, 0x5B, 0x4F,
  0x66, 0x6D, 0x7D, 0x07,
  0x7F, 0x67, 0x77, 0x7C,
  0x39, 0x5E, 0x79, 0x71,
  0x00
};

#define HLT = 0b100000000000000
#define MI  = 0b010000000000000
#define RI  = 0b001000000000000
#define RO  = 0b000100000000000
#define IO  = 0b000010000000000
#define II  = 0b010001000000000
#define AI  = 0b010000100000000
#define AO  = 0b010000010000000
#define SM  = 0b010000001000000
#define SU  = 0b010000000100000
#define BI  = 0b010000000010000
#define OI  = 0b010000000001000
#define CE  = 0b010000000000100
#define CO  = 0b010000000000010
#define J  =  0b010000000000001

uint16_t data[]={
  MI|CO,    RO|II|CE,   0,        0,        0,          0,    0,    0                  //0000 -NOP
  MI|CO,    RO|II|CE,   MI|IO,    RO|AI,    0,          0,    0,    0                  //0001 -LOAD A
  MI|CO,    RO|II|CE,   MI|IO,    RO|BI,    AI|SM,      0,    0,    0                  //0010 -ADDITION
  MI|CO,    RO|II|CE,   MI|IO,    RO|BI,    AI|SM|SU,   0,    0,    0                  //0011 -SUBSTRACTION
  MI|CO,    RO|II|CE,   MI|IO,    RI|AO,    0,          0,    0,    0                  //0100 -STORE A
  MI|CO,    RO|II|CE,   IO|AI,    0,        0,          0,    0,    0                  //0101 -LOAD IMMEDIATE
  MI|CO,    RO|II|CE,   IO|J,     0,        0,          0,    0,    0                  //0110 -JUMP
  MI|CO,    RO|II|CE,   0,        0,        0,          0,    0,    0                  //0111
  MI|CO,    RO|II|CE,   0,        0,        0,          0,    0,    0                  //1000
  MI|CO,    RO|II|CE,   0,        0,        0,          0,    0,    0                  //1001
  MI|CO,    RO|II|CE,   0,        0,        0,          0,    0,    0                  //1010
  MI|CO,    RO|II|CE,   0,        0,        0,          0,    0,    0                  //1011
  MI|CO,    RO|II|CE,   0,        0,        0,          0,    0,    0                  //1100
  MI|CO,    RO|II|CE,   0,        0,        0,          0,    0,    0                  //1101 
  MI|CO,    RO|II|CE,   AO|OI,    0,        0,          0,    0,    0                  //1110 -OUTPUT
  MI|CO,    RO|II|CE,   HLT,      0,        0,          0,    0,    0                  //1111 -HALT SYSTEM
}; 

void setup() {

  // Output Pins, def=read
  for (int i = 0; i < 8; i++) {
    pinMode(outPins[i], INPUT);
  }

  // Address Pins
  for (int i = 0; i < 12; i++) {
    pinMode(addPins[i], OUTPUT);
  }

  // Control Pins, default=Read
  pinMode(pinW, OUTPUT);
  pinMode(pinG, OUTPUT);
  pinMode(pinE, OUTPUT);
  setReadMode();

  Serial.begin(115200);


  delay(1000);

  Serial.println("\nWriting to EEPROM:");
  //debug();
  writeDigits();
  writeHex();
  //writeEEPROM();

  Serial.println("\nReading from EEPROM:");
  readEEPROM();

}

void loop() {

}
